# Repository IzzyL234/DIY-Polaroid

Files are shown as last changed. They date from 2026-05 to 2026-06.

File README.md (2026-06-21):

# DIY-Polaroid
This is a DIY polaroid using a thermal printer, an ESP32-CAM, and a battery! It allows you to take pictures and have them printed out, in black in white, in real time on receipt paper. 

As someone who loves to take photos and keeps lots of instant camera/photo booth photos at home, I excitedly bought a polaroid a couple years ago. However, due to the high cost of polaroid film, I have unfortunately only used it sparingly, unable to capture daily moments with my friends, pets, and family, as I had initially hoped for. With this thermal printer and camera duo, I will be able to take photos in a similar style of instant cameras, but without having to worry about wasting film or money! On Amazon, you can find thermal paper worth $0.7 per roll and on AliExpress, $0.33 per roll. 

This is also a fun way for me to learn more about hardware!



<br/>
Build Video: (https://youtu.be/IADWq9CQPvw)

<span style="color: #2ECC71;">How it Works:</span>
----
Diagram 1:
<br/><br/>


1. Pressing the shutter button sends a message to the ESP32-CAM to take a picture
2. Once a picture is taken, the ESP32 processes the image and converts it into a black-and-white bitmap suitable for thermal printing.
3. The processed image data is sent to the thermal printer through a serial (TTL) connection.
4. The thermal printer prints the image onto receipt paper in real time.
5. The entire system is powered by a Dewalt 12V battery connected to a buck converter, which safely steps the voltage down to 5V for the ESP32-CAM and printer.

Other notes:
- Copper wires will be used to connect battery to buck converter and will be screwed in
- Dupont wires will be used for the ESP32-CAM connections
- Power Reqs: 3.5 or 5v for ESP32-CAM and 12V for printer

Other Details:
------
[STEP files and Full Assembly](Design_Submission_Materials)
  
- printer details:



__________________________________________________
## Assembly Instructions!

### 1. Print the enclosure parts
3D print the main enclosure pieces:

- `top.step`
- `bottom_box.step`
- `outside_box.step`

### 2. Prepare the electronics
Gather the main components:

- ESP32-CAM
- Thermal printer
- Shutter button
- Battery or power adapter
- Wires/jumper cables

### 3. Fit the components inside

Note: The button will be placed through the hole at the top and is the only functional button. The others are part of the outer casing design. The printer rests on a platform with areas for the wires to go through. The buck converter and ESP32 CAM will be secured to the sides with snap pieces. The top will stay on by itself, it is secured with a fitted lid.
<br/><br/>


<br/><br/>
Side View:
<br/>

<br/><br/>

Side Note: All the failed prototypes that went into perfecting the casing design...

<br><br>
#### Steps:
1. Place the ESP32-CAM inside the enclosure so the camera lens lines up with the front opening. It should snap into place.
2. Place the buck converter inside the enclosure under the ESP32-CAM. It should snap into place. .
3. Slide the battery adapter onto the battery and slide it into the bottom section of the enclosure. The wire should go up through the cut out on the side.
4. Place the thermal printer on top of the platform so that the wires from the bottom fit through the cutout on the platform.
5. Wires should snap into place on the sides.
6. Connect the button to the wire and loop the wire through the hole in the cap. 

See diagram above for visual details. 

### 6. Wiring
Connect the ESP32-CAM to the thermal printer using serial communication.

Wiring: see wiring diagram below


## Firmware Instructions
### 1. Upload the file "polaroid code" into Arduino as a sketch and upload to the ESP32
Double check that the pins noted in the code match what you actually have wired.

To use:
---
1. Press and hold button on top for 2 sec. 
2. press the capture button at the top once
3. wait for the photo to print out from the top!
4. to power off, open the bottom again and slide the battery off

BOM:
---
| Item | Link | Cost |
--- | --- | --- |
| Battery |(https://www.aliexpress.us/item/3256811448662800.html) | $11.54 |
| ESP32-CAM + wires + FDTI | (https://www.amazon.com/Freenove-Dual-core-Microcontroller-Wireless-Projects/dp/B0CJJHXD1W)) | $6.58 | 
| Thermal Printer (film roll included) | (https://www.aliexpress.us/item/3256809632695801.html) | $19.69 |
| Button | (https://www.amazon.com/dp/B07PPD7LWB) | $6.99 | 
| Battery Adapter | (https://www.amazon.com/dp/B09N42RJKW) | $16.90 | 
---------------
Total cost: $61.70

[BOM csv](Design_Submission_Materials)
<br/>

Cost of Polaroid: $149.99 (no film included) :(

Some sources for inspiration:
1. https://www.hackster.io/Mellow_labs/build-your-own-esp32-instant-camera-f12649
2. https://community.dfrobot.com/makelog-308490.html

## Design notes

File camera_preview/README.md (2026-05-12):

-Basic firmware for ESP32-CAM

-This is test code to preview the camera streaming from the ESP-32 CAM

-This is a reference for the final code used to run the DIY-Polaroid once the physical printer arrives 

-This code is taken from the Arduino library

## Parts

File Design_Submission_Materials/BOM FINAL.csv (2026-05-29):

Item | Link | Cost ($)
Battery | https://www.aliexpress.us/item/3256811448662800.html | 11.54
ESP32-CAM+wires+FTDI | https://www.amazon.com/Freenove-Dual-core-Microcontroller-Wireless-Projects/dp/B0CJJHXD1W | 6.58
Thermal Printer (with film roll) | https://www.aliexpress.us/item/3256809632695801.html | 19.69
Button | https://www.amazon.com/dp/B07PPD7LWB | 6.99
Battery Adapter | https://www.amazon.com/dp/B09N42RJKW | 16.9
Total Cost: $61.70
*Note: I purchased these items already or got them from already existing materials at home

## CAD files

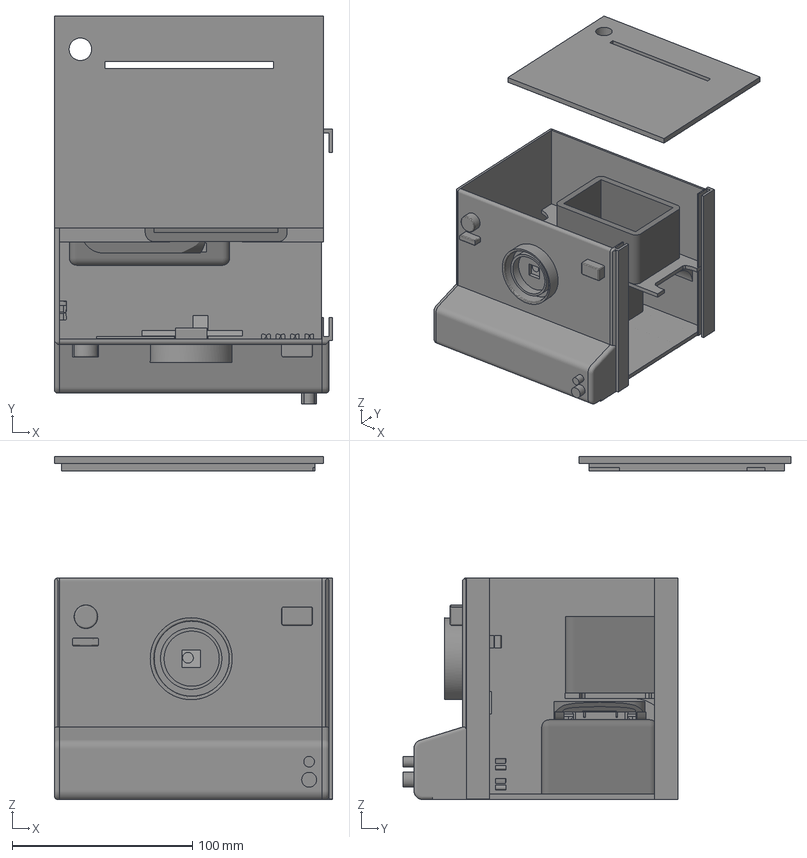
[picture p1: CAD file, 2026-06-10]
Design_Submission_Materials/CAD Files/Full Assembly.3mf
154.5 x 215.3 x 190.4 mm
MeshBody1 x 2

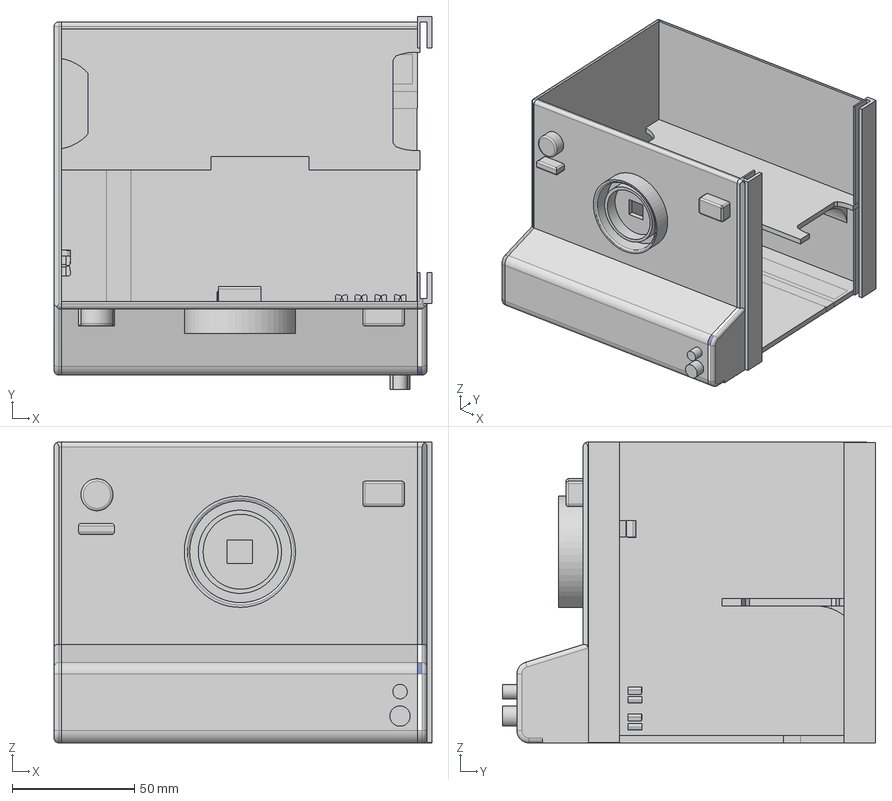
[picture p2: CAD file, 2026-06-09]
Design_Submission_Materials/CAD Files/Outside Box.step
154.5 x 152.7 x 123.0 mm

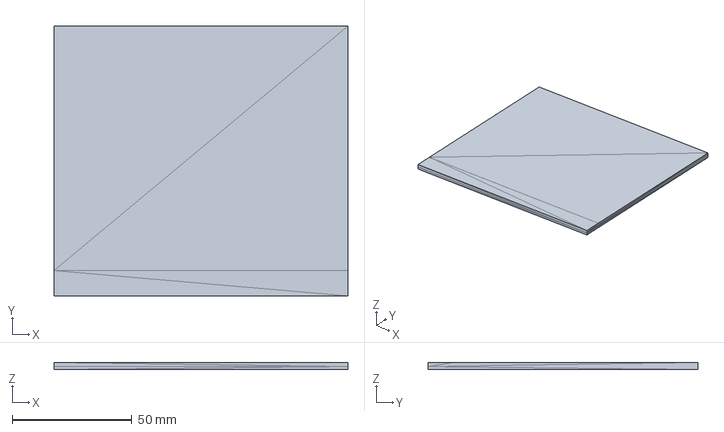
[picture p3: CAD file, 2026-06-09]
Design_Submission_Materials/CAD Files/Sliding Door.step
123.0 x 112.9 x 3.01 mm

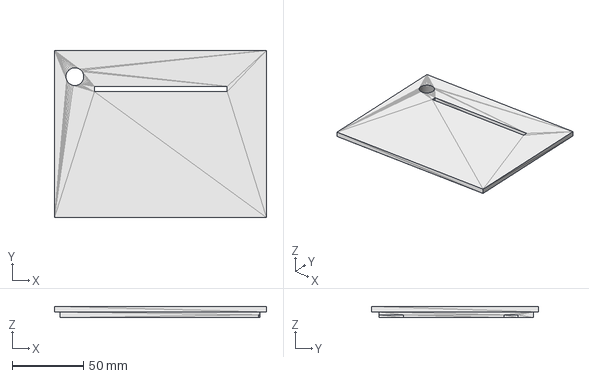
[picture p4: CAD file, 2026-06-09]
Design_Submission_Materials/CAD Files/Top of Box.step
149.2 x 117.6 x 8.00 mm

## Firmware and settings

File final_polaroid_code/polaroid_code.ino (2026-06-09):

#include "esp_camera.h"
#include "esp_sleep.h"

#define CAMERA_MODEL_WROVER_KIT
#include "camera_pins.h"

HardwareSerial printerSerial(1);

// IMPORTANT: use GPIO13, not GPIO7.
// GPIO13 supports deep sleep wake.
const int buttonPin = 13;

const unsigned long HOLD_TIME = 2000; // 2 seconds

bool buttonWasDown = false;
unsigned long buttonDownStart = 0;
bool longPressHandled = false;

void enterOffMode() {
  Serial.println("Turning off / entering deep sleep...");
  delay(300);

  // Wake up when buttonPin goes LOW
  esp_sleep_enable_ext0_wakeup((gpio_num_t)buttonPin, 0);

  esp_deep_sleep_start();
}

bool buttonHeldForTwoSeconds() {
  unsigned long startTime = millis();

  while (digitalRead(buttonPin) == LOW) {
    if (millis() - startTime >= HOLD_TIME) {
      return true;
    }
    delay(10);
  }

  return false;
}

void waitForButtonRelease() {
  while (digitalRead(buttonPin) == LOW) {
    delay(10);
  }
  delay(200); // debounce
}

void setup() {
  Serial.begin(115200);

  pinMode(buttonPin, INPUT_PULLUP);

  /*
    Battery always connected behavior:

    - When battery is first connected, the ESP32 starts.
    - If the button is NOT being held for 2 seconds, it goes to sleep.
    - To turn on, hold the shutter button for 2 seconds.
  */

  if (esp_sleep_get_wakeup_cause() == ESP_SLEEP_WAKEUP_EXT0) {
    Serial.println("Woke up from button press.");

    if (!buttonHeldForTwoSeconds()) {
      Serial.println("Button was not held long enough. Going back to sleep.");
      enterOffMode();
    }

    Serial.println("Held for 2 seconds. Turning on.");
    waitForButtonRelease();
  } 
  else {
    Serial.println("Cold boot / battery connected.");

    if (!buttonHeldForTwoSeconds()) {
      Serial.println("Button was not held for startup. Going to sleep.");
      enterOffMode();
    }

    Serial.println("Startup hold detected. Turning on.");
    waitForButtonRelease();
  }

  camera_config_t config;

  config.ledc_channel = LEDC_CHANNEL_0;
  config.ledc_timer = LEDC_TIMER_0;

  config.pin_d0 = Y2_GPIO_NUM;
  config.pin_d1 = Y3_GPIO_NUM;
  config.pin_d2 = Y4_GPIO_NUM;
  config.pin_d3 = Y5_GPIO_NUM;
  config.pin_d4 = Y6_GPIO_NUM;
  config.pin_d5 = Y7_GPIO_NUM;
  config.pin_d6 = Y8_GPIO_NUM;
  config.pin_d7 = Y9_GPIO_NUM;

  config.pin_xclk = XCLK_GPIO_NUM;
  config.pin_pclk = PCLK_GPIO_NUM;
  config.pin_vsync = VSYNC_GPIO_NUM;
  config.pin_href = HREF_GPIO_NUM;

  config.pin_sscb_sda = SIOD_GPIO_NUM;
  config.pin_sscb_scl = SIOC_GPIO_NUM;

  config.pin_pwdn = PWDN_GPIO_NUM;
  config.pin_reset = RESET_GPIO_NUM;

  config.xclk_freq_hz = 20000000;
  config.pixel_format = PIXFORMAT_GRAYSCALE;
  config.frame_size = FRAMESIZE_CIF;
  config.fb_count = 1;
  config.grab_mode = CAMERA_GRAB_LATEST;

  esp_err_t err = esp_camera_init(&config);

  if (err != ESP_OK) {
    Serial.println("Camera init failed");
    return;
  }

  printerSerial.begin(9600, SERIAL_8N1, -1, 5);
  delay(3000);

  Serial.println("Device is on. Short press = capture. Hold 2 sec = off.");
}

void loop() {
  bool buttonDown = digitalRead(buttonPin) == LOW;

  if (buttonDown && !buttonWasDown) {
    // button was just pressed
    buttonWasDown = true;
    buttonDownStart = millis();
    longPressHandled = false;
  }

  if (buttonDown && buttonWasDown) {
    // button is being held
    if (!longPressHandled && millis() - buttonDownStart >= HOLD_TIME) {
      longPressHandled = true;
      enterOffMode();
    }
  }

  if (!buttonDown && buttonWasDown) {
    // button was released
    unsigned long pressLength = millis() - buttonDownStart;
    buttonWasDown = false;

    if (!longPressHandled && pressLength < HOLD_TIME) {
      Serial.println("Short press: capture and print");
      takePhotoAndPrint();
    }

    delay(200); // debounce
  }

  delay(20);
}

void takePhotoAndPrint() {
  camera_fb_t* fb = takePhoto();
  if (fb == NULL) {
    Serial.println("Photo failed");
    return;
  }

  uint8_t* resized = resizeImage(fb);
  uint8_t* dithered = applyDithering(resized, 384, 288);
  uint8_t* bitmap = convertImage(dithered, 384, 288);

  printImage(bitmap, 384, 288);

  esp_camera_fb_return(fb);

  // dithered points to the same memory as resized,
  // so only delete resized once.
  delete[] resized;
  delete[] bitmap;

  delay(1000);
}

bool ifButtonPressed() {
  return digitalRead(buttonPin) == LOW;
}

camera_fb_t* takePhoto() {
  camera_fb_t* fb = esp_camera_fb_get();
  return fb;
}

uint8_t* resizeImage(camera_fb_t *input) {
  int originalWidth = input->width;
  int originalHeight = input->height;
  int newWidth = 384;
  int newHeight = 288;

  uint8_t *resizedImage = new uint8_t[newWidth * newHeight];

  for (int y = 0; y < newHeight; y++) {
    for (int x = 0; x < newWidth; x++) {
      int sourceX = x * originalWidth / newWidth;
      int sourceY = y * originalHeight / newHeight;

      resizedImage[y * newWidth + x] =
        input->buf[sourceY * originalWidth + sourceX];
    }
  }

  return resizedImage;
}

uint8_t* applyDithering(uint8_t *img, int width, int height) {
  for (int y = 0; y < height; y++) {
    for (int x = 0; x < width; x++) {
      int i = y * width + x;

      int oldPixel = img[i];

      int newPixel;

      if (oldPixel < 128)
        newPixel = 0;
      else
        newPixel = 255;

      img[i] = newPixel;

      int error = oldPixel - newPixel;
      int spread = error / 8;

      auto addError = [&](int xx, int yy) {
        if (xx < 0 || xx >= width || yy < 0 || yy >= height)
          return;

        int index = yy * width + xx;

        int value = img[index] + spread;

        if (value < 0)
          value = 0;

        if (value > 255)
          value = 255;

        img[index] = value;
      };

      addError(x + 1, y);
      addError(x + 2, y);

      addError(x - 1, y + 1);
      addError(x, y + 1);
      addError(x + 1, y + 1);

      addError(x, y + 2);
    }
  }

  return img;
}

uint8_t* convertImage(uint8_t* image, int width, int height) {
  int bytesPerRow = (width + 7) / 8;
  int bitmapSize = bytesPerRow * height;

  uint8_t* bitmap = new uint8_t[bitmapSize];

  for (int y = 0; y < height; y++) {
    for (int byteX = 0; byteX < bytesPerRow; byteX++) {
      uint8_t b = 0;

      for (int bit = 0; bit < 8; bit++) {
        int x = byteX * 8 + bit;

        if (x < width) {
          int pixelIndex = y * width + x;
          uint8_t pixel = image[pixelIndex];

          // black pixel if grayscale value is dark
          if (pixel < 128) {
            b |= (1 << (7 - bit));
          }
        }
      }

      bitmap[y * bytesPerRow + byteX] = b;
    }
  }

  return bitmap;
}

void printImage(uint8_t* bitmap, int width, int height) {
  int bytesPerRow = (width + 7) / 8;

  printerSerial.write(0x1D);
  printerSerial.write(0x76);
  printerSerial.write(0x30);
  printerSerial.write(0x00);

  printerSerial.write(bytesPerRow & 0xFF);
  printerSerial.write((bytesPerRow >> 8) & 0xFF);

  printerSerial.write(height & 0xFF);
  printerSerial.write((height >> 8) & 0xFF);

  for (int i = 0; i < bytesPerRow * height; i++) {
    printerSerial.write(bitmap[i]);
  }

  printerSerial.write(0x0A);
}

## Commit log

2026-05-04 Add BOM section to README
    Added a Bill of Materials (BOM) section to the README.
2026-05-04 Update README with project description and BOM
2026-05-04 Correct BOM table formatting in README
    Fix formatting issues in the BOM section.
2026-05-04 Update BOM with battery item details
2026-05-04 Revise BOM with updated links and prices
    Updated links and costs for various components in the BOM.
2026-05-04 Update BOM with new item links and costs
2026-05-04 Revise BOM links and prices in README
    Updated links and prices for various components in the BOM section.
2026-05-04 Update BOM with new links and prices
2026-05-10 Update README with project details and BOM
    Expanded the project description and added a Bill of Materials (BOM) section with item links and costs.
2026-05-10 Enhance README with project motivation and cost details
    Added personal motivation and cost comparison for using a thermal printer with the DIY polaroid project.
2026-05-10 Add BOM section with battery item details
2026-05-10 Update BOM section with item links and costs
    Added detailed BOM with links and costs for components.
2026-05-10 Specify Dewalt 12V battery in README
2026-05-10 Update README with wiring and component notes
    Added additional notes on wiring and component securing.
2026-05-12 Create CameraPreviewCode
2026-05-12 Update README with printer details and images
2026-05-12 Add README for DIY Polaroid camera firmware
    This README provides an overview of the firmware functionality and code flow for the DIY Polaroid camera project, including the file structure.
2026-05-12 Add CameraWebServer.ino to camera_preview directory
2026-05-12 Fix formatting issues in BOM.csv
    Removed extra commas and adjusted formatting.
    [BOM.csv]
2026-05-12 Update and rename test to CAD Link
2026-05-12 Rename CAD Link to CAD Link.md
2026-05-12 Update CAD Link.md
2026-05-12 Add camera setup header for ESP32-CAM
2026-05-12 Create printer_setup.h for thermal printer setup
    Added setup functions for thermal printer communication.
2026-05-12 Add image processing function for thermal printer
2026-05-12 Clarify power requirements in README
    Updated power requirements for ESP32-CAM and printer.
2026-05-12 Rename [V2] Camera DIY.f3z to [FULL MODEL] Camera DIY.f3z
    [[FULL MODEL] Camera DIY.f3z, [V2] Camera DIY.f3z]
2026-05-12 Update [FULL MODEL] Camera DIY.f3z
    [[FULL MODEL] Camera DIY.f3z]
2026-06-02 Revise README with assembly notes and images
    Updated assembly notes and added images for clarity.
2026-06-02 Update button description in README
    Clarified the description of the functional button in the CAD details section.
2026-06-04 Enhance README with firmware and wiring details
    Add firmware instructions and update notes in README
2026-06-09 Update README with code flow and remove placeholders
    Removed untested code notes and clarified overall code flow for the DIY Polaroid camera firmware.
2026-06-09 Refactor button handling and sleep mode logic
2026-06-10 Rename 3dpea.com_Top V3.step to Top of Box.step
    [Top of Box.step]
2026-06-10 Add Outside Box CAD file
    [Outside Box.step]
2026-06-10 Rename [V3] Camera DIY.step to Full Assembly.step
    [Full Assembly.step]
2026-06-10 Rename [V3] Camera DIY.3mf to Full Assembly.3mf
    [Full Assembly.3mf]
2026-06-10 Add Sliding Door CAD file
    [Sliding Door.step]
2026-06-10 Refactor assembly instructions in README.md
    Removed redundant instructions for placing components in the enclosure while retaining the essential steps.
